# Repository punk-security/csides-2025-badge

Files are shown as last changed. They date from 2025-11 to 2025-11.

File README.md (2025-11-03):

# This is the repo for the CSIDES 2025 crab badge

**This badge is a litle bit funky as we ported the TV-B-GONE code to this badge so you cna use it to turn off most TVs**

This is our most complex badge to date, with quite a few extra components. Soldering it is not easy.

The badge is printed with full-colour UV printed silkscreen. Usually we use JLCPCB for this (and to be honest they're quality is better in our opinion) but they cant print full-colour onto a HASL (silver) finished board. They can only do it with ENIG, which is the gold look. As this crab is meant to be a cyborg, we had to go with PCBWAY this time. 

As with other badges, we made the first design in AutoCAD EAGLE. It's just easy to use, and we're really familiar with it. Then we export it as a gerber and include the silkscreen file manually. This is then provided to PCBWAY. That gerber is in this repo, so you can skip all that.

### TV-B-GONE

For a long time, we've wanted to do a badge which can turn TVs off. A cybord crab, with it's little eye stalk things seemed like our perfect opportunity. It took a lot of work to get the code to work, and tweak the circuitry to get a good range.

Go check out the original code - https://github.com/shirriff/Arduino-TV-B-Gone  
... and the main website- https://www.tvbgone.com/  
... and this instructables - https://www.instructables.com/4-DIY-TV-B-Gone/  
... and this one - https://www.instructables.com/350-DIY-TV-B-Gone-Mico/

We really stood on the shoulders of giants with this, and hopefully added a new and interesting twist. The range is pretty good thanks to a capacitor, which is loosely optimised through trial and error. Essentially you want it to charge as as quickly as possible to not impact the microcontroller, but not discharge completely during a signal transmission. Also size / cost etc.

The badge has a potentiometer so you can control the resistance to the LEDs, and therefore limit their current draw. On fresh batteries, you can go full power and get 20-25m of range. As the batteries run low, the badge will keep crashing as you try to transmit so just tweak the pot.

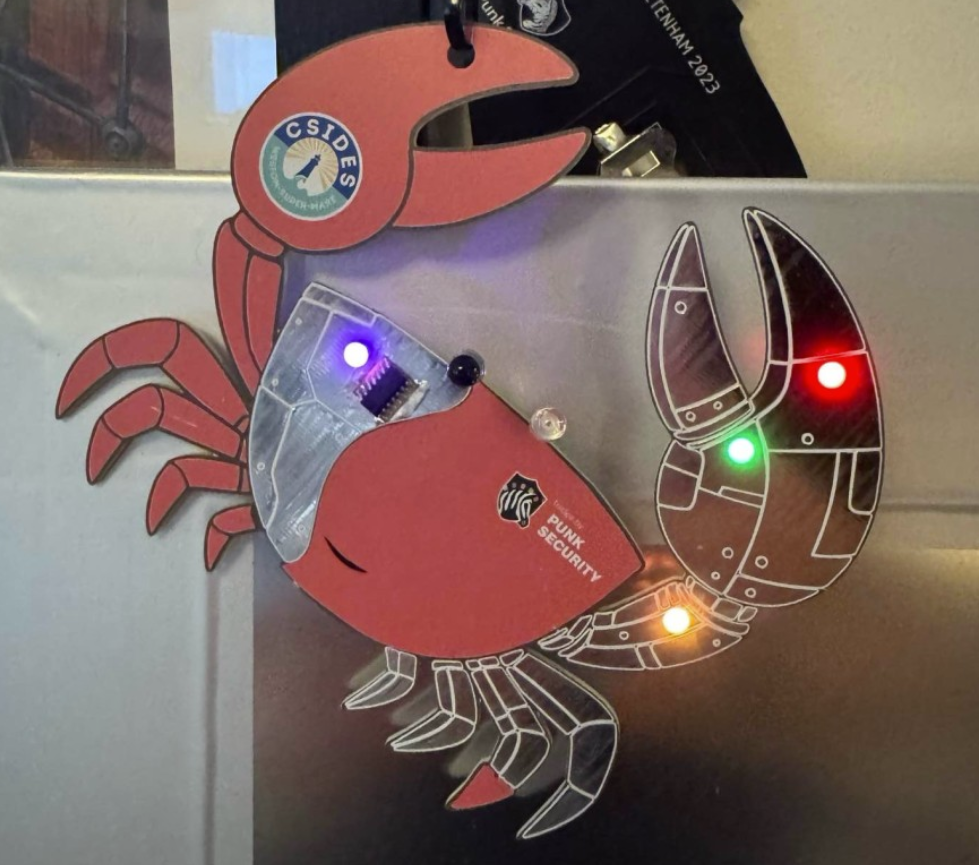
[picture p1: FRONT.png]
PCB Front

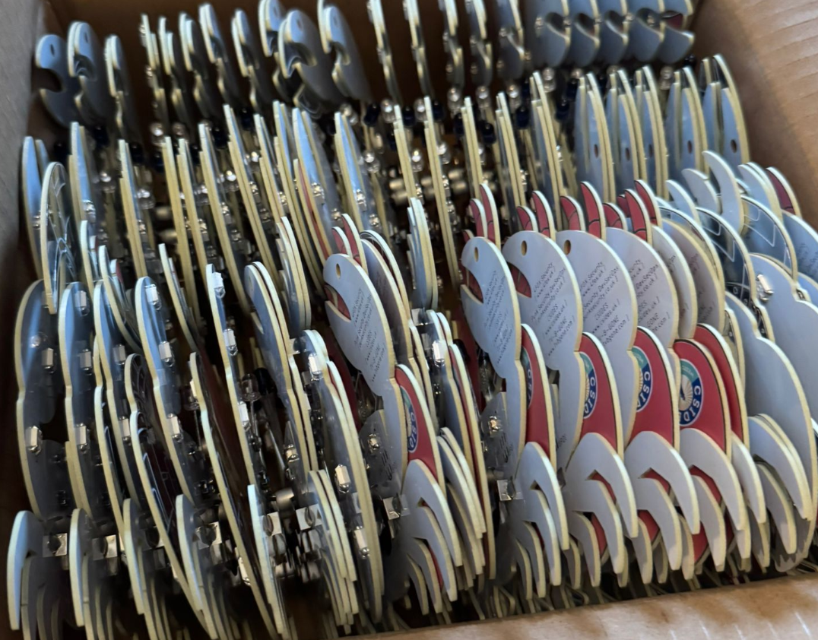
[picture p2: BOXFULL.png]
PCBs


Lots of things in this repo:

- EAGLE.brd: The AutoCAD Eagle board design
- EAGLE.sch: The AutoCAD Eagle circuit schematic
- gerber.zip: the file you can upload to JLCPCB and order your own badge, as is
- SILK_TOP.png: the full colour silkscreen print
- firmware.ino: the arduino code that powers the badge, which you can modify and flash via the SAO connector
- main.h: This is part of the TV-B-GONE code we ported
- WORLD_IR_CODES.h: More of the TV-B-GONE code

## Bill Of Materials

There are a lot of components with this badge. It started out on a breadboard and we tried to keep the part count as low as possible whilst making it actually work! The transistors are a right pain to solder!

This is our first badge using a 1614 microcontroller too. We couldn't fit the code onto the usual ATTINY412.

Essentially its:

* ATTINY1614 microcontroller
* Button - any surface mount button fitting the footprint will work
* NC Button - The reset button it the same footprint as the usual button, but is "open" when pressed. You can skip this and just solder the pads together if you prefer.
* CR2032 battery clip x 2 - surface mount not through hole
* Neopixel 5050 addressable LED - Definitely get the right version of these
* 100 Ohm Trimmer - TC33X-2-101E
* Aishi 100uF Cap - EMK0JM101E83D00R
* NPN transistor SOT-23 - MMBT3904
* 940nm IR LEDS - We had 2 different ones - 10 degree and 40 degree transmission beams

## How does it work?

The badge does the usually blinky modes, but also turns TV off.

To cycle flashy modes, you just short press the button on the badge. 

It can also turn TVs off. To do this, hold the button in for around 3 or 4 seconds and then loose. The badge will start flashing green in one LED. Every LED flash is another European TV off code. When its run out of codes, it will start flashing blue. These are the US codes. When its run out of those, it will return to normally flashy mode. You can exit early at any point by simply pressing the button again.

Holding the button in for a long time will cause the badge to go to sleep. It will do this itself after 60 mins-ish.

## Ordering your own badge

We've uploaded the AutoCAD EAGLE schematic and board design!  You will probably have to do some tweaks to get it working as they're not designed to be standalone exports.

We've also uploaded the gerber.zip.  Take this to PCBWAY and you can order your own exact copies of the board :)

## Writing and flashing code!

We use [MegaTinyCore](https://github.com/SpenceKonde/megaTinyCore) for the arduino interface.

Dev and flashing is done within the Arduino IDE ( < v2 ) using a jtag2updi interface, as discussed [here](https://github.com/SpenceKonde/AVR-Guidance/blob/master/UPDI/jtag2updi.md)

We use [these little usb sticks](https://amzn.eu/d/c0lx0wG), with a 4.7k resistor soldered between the Tx and Rx lines.  

### Installing MegaTinyCore dependencies

This board package can be installed via the board manager in arduino. The boards manager URL is:

`http://drazzy.com/package_drazzy.com_index.json`

1. File -> Preferences, enter the above URL in "Additional Boards Manager URLs"
2. Tools -> Boards -> Boards Manager...
3. Wait while the list loads (takes longer than one would expect, and refreshes several times).
4. Select "megaTinyCore by Spence Konde" and click "Install". For best results, choose the most recent version.

### Setting up the IDE

1. Open the file **firmware.ino** in arduino
2. Select tools > Board > megaTinyCore > ATtiny412/402/212/202
3. Select tools > Chip > ATtiny412
4. Select tools > Clock > 16Mhz internal *(it wont turn off TVs otherwise)*
5. Select tools > Programmer > SerialUPDI SLOW
6. Select tools > Port > ( pick your COM port)

### Flashing firmware
1. Connect the 3v3 pin to 3v on your usb (maybe wedge it in the battery clip)
2. Connect GND to GND
3. Connect UPDI to the RxD port
4. Click Upload button

## How to solder?

It's super tricky!

Essentially, line up the parts and solder them.

We placed the ATTINY1614 on the front as it looked quite cool. It's horrible to solder. Line up the micontroller dimple with the circle, and try not to bridge the pins with the crabs metal background. 

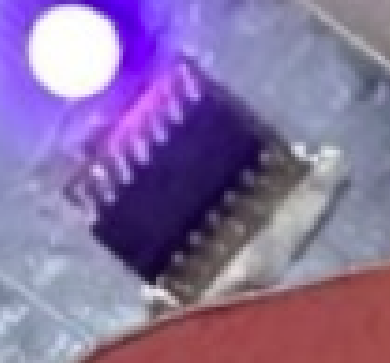
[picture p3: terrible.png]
Terrible


The back is also tricky. Most parts are obvious. The RST button should be a normally closed button, or just solder a bit of wire in its place. The triangles near the LED placements show you how to rotate the LEDs into position.

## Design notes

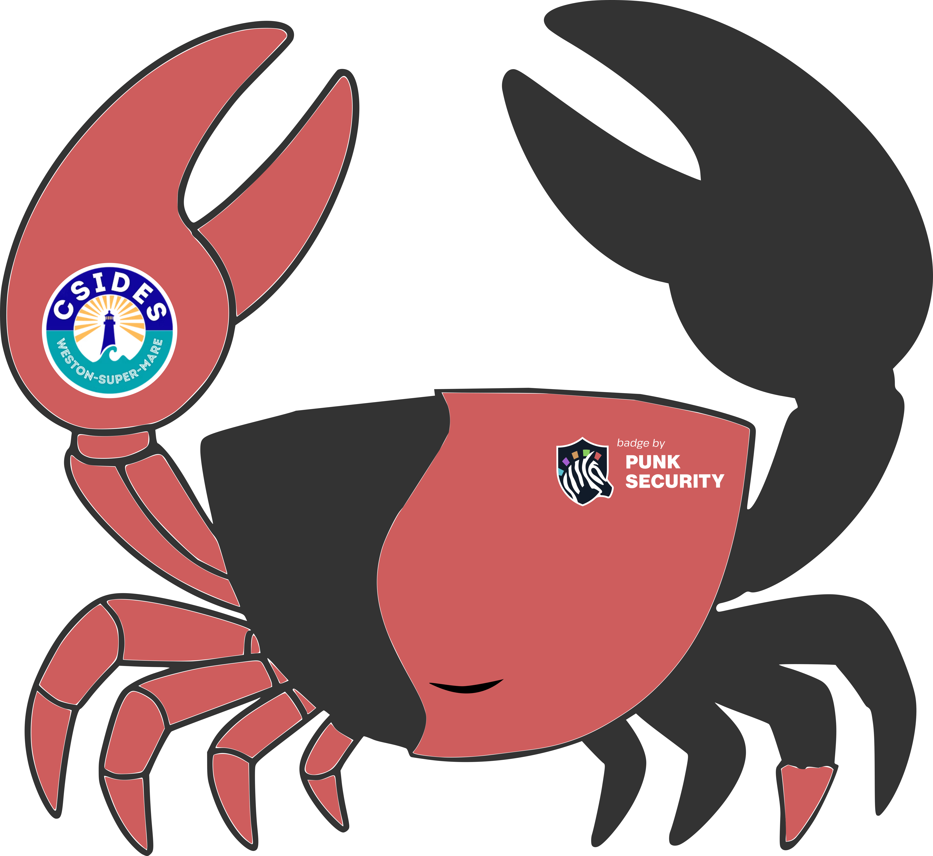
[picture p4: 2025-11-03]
SILK_TOP.png

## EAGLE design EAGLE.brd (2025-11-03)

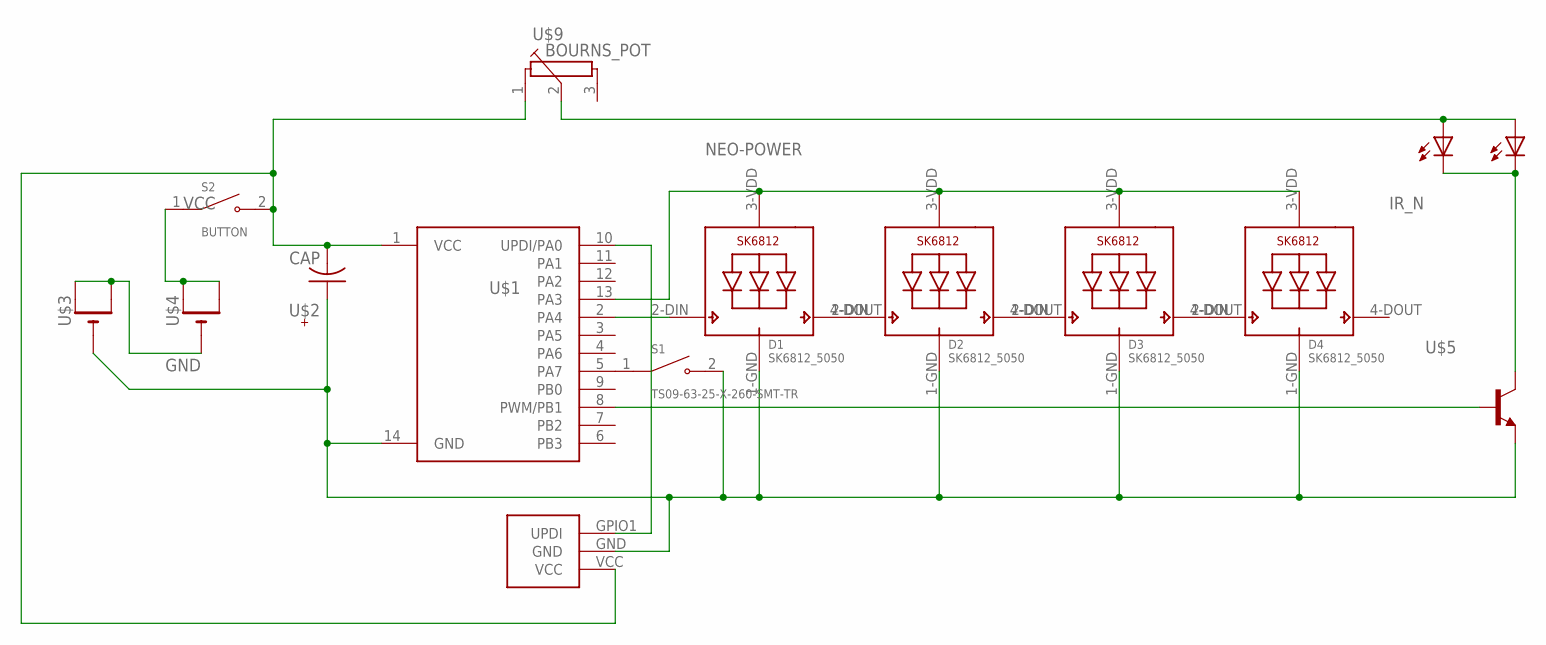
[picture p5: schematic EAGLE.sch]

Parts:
D1, D2, D3, D4: SK6812_5050; SK6812_REVERSE_W_CUT
S1: TS09-63-25-X-260-SMT-TR; SW_TS09-63-25-X-260-SMT-TR
S2: BUTTON; SW_TS09-63-25-X-260-SMT-TR
U$1: ATTINY1614ATTINY1614; SO14
U$2: CAP; UD-6,3X5,8_NICHICON
U$3, U$4: CR2032SMT; CR2032-SMD
U$5: NPN; SOT23
U$6, U$7: LEDSIDESOLDER; LED3MM_5MM_SIDESOLDER
U$8: SAO; SAO_SMD
U$9: BOURNS_POT; 3223W

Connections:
GND: D1.1-GND (GND), D2.1-GND (GND), D3.1-GND (GND), D4.1-GND (GND), S1.2, U$1.14 (GND), U$2.+, U$3.GND, U$5.2 (E), U$8.GND
IR_N: U$5.3 (C), U$6.KN (C), U$7.KN (C)
IR_PWR: U$6.AN (A), U$7.AN (A), U$9.2 (1S)
unnamed: S1.1, U$1.5 (PA7)
unnamed: D1.4-DOUT (DO), D2.2-DIN (DI)
unnamed: D2.4-DOUT (DO), D3.2-DIN (DI)
unnamed: D3.4-DOUT (DO), D4.2-DIN (DI)
unnamed: S2.1, U$4.+$1 (+), U$4.+$2 (+1)
unnamed: U$3.+$1 (+), U$3.+$2 (+1), U$4.GND
NEO-POWER: D1.3-VDD (VDD), D2.3-VDD (VDD), D3.3-VDD (VDD), D4.3-VDD (VDD), U$1.13 (PA3)
NEO_SIGNAL: D1.2-DIN (DI), U$1.2 (PA4)
PWM: U$1.8 (PWM/PB1), U$5.1 (B)
UPDI: U$1.10 (UPDI/PA0), U$8.GPIO1 (UPDI)
VCC: S2.2, U$1.1 (VCC), U$2.-, U$8.VCC, U$9.1 (1A)

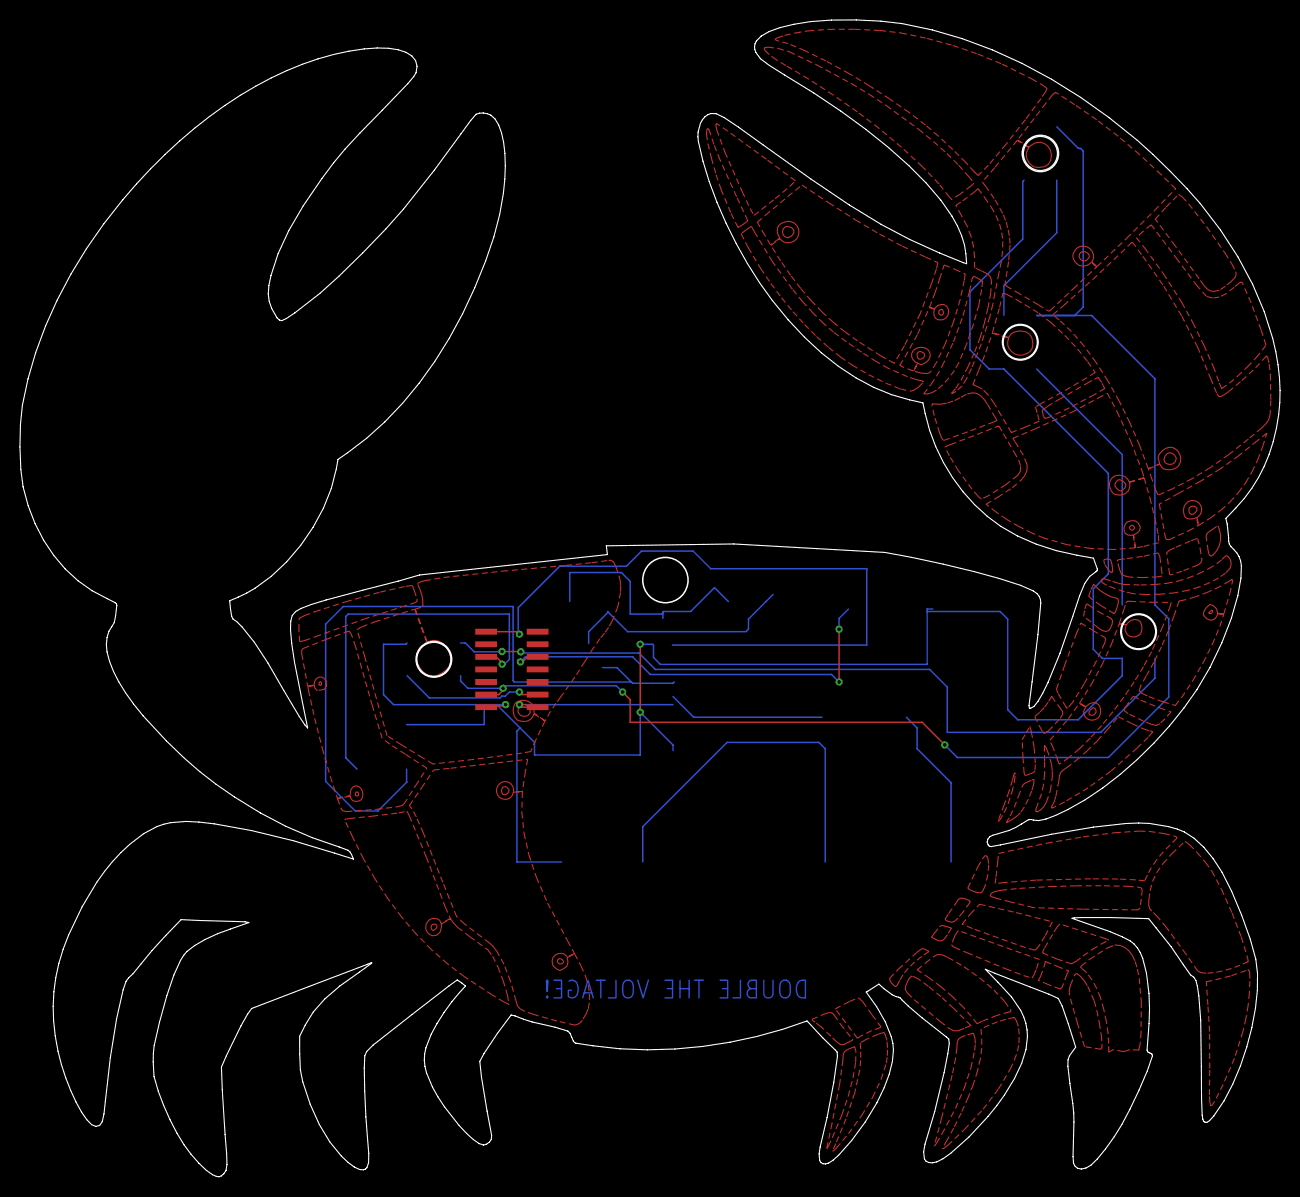
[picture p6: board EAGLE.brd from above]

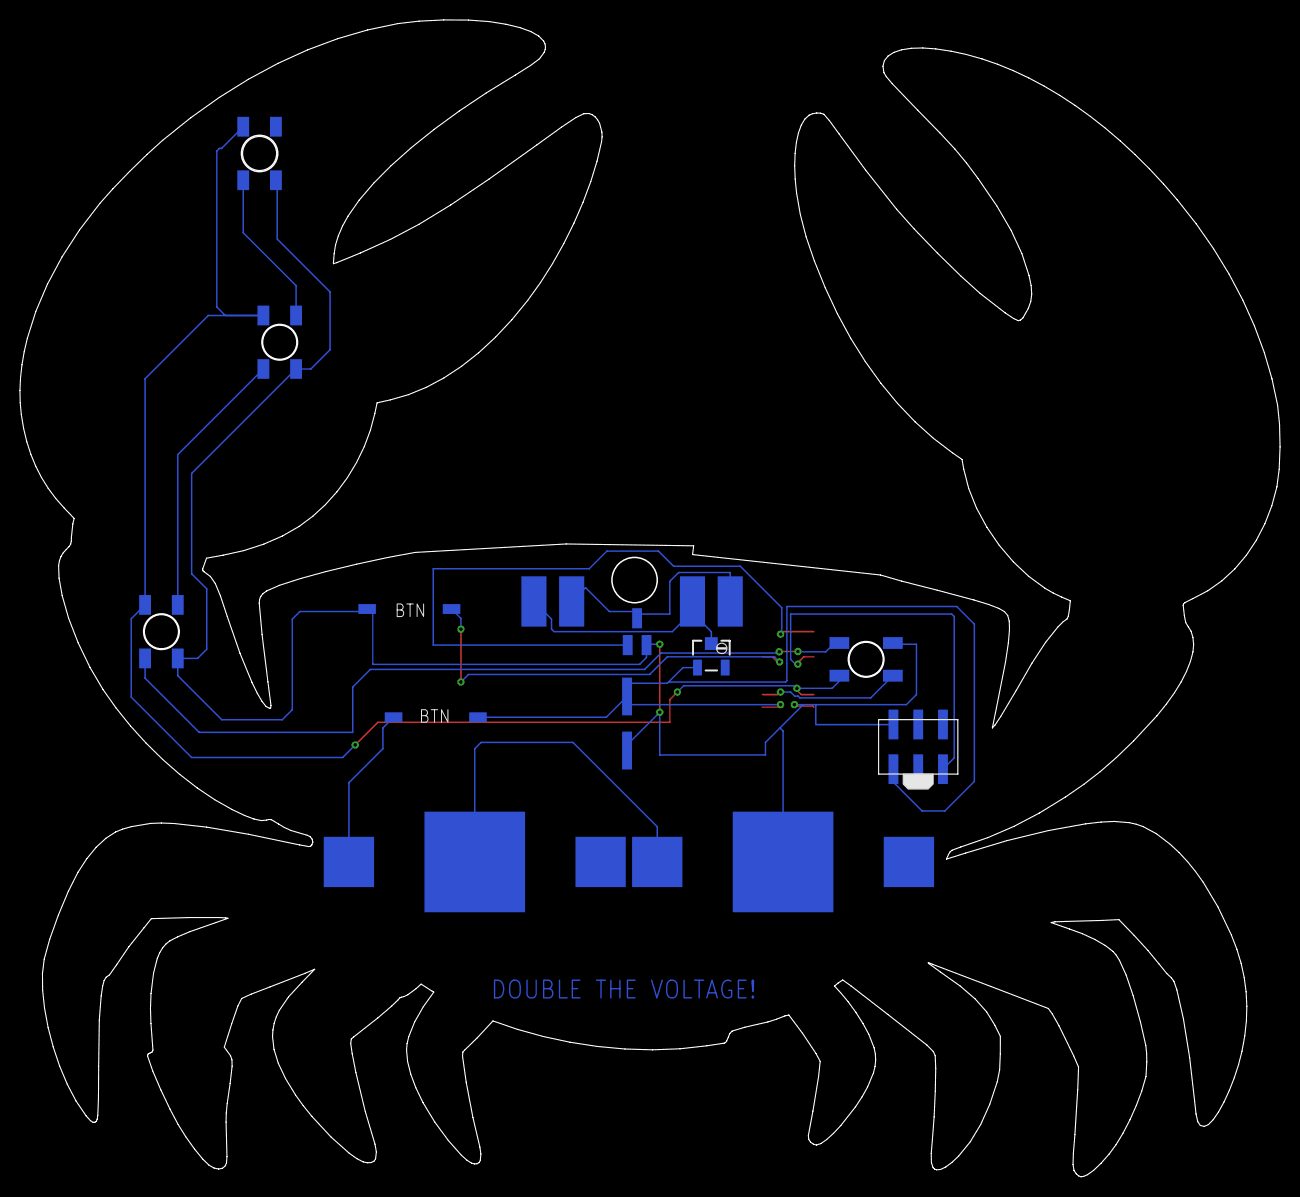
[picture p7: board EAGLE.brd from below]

Board: 2 copper layers, 127.2 x 116.8 mm, 15 parts (14 on the bottom side), 14 nets.

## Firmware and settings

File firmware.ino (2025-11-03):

#include <avr/io.h>
#include <avr/interrupt.h>
#include <avr/sleep.h>
#include <util/delay.h>
#include <avr/pgmspace.h>

/// FLASH at 16Mhz otherwise it no worky
/// Set to starutp time 64 ms to prevent reset button corruption

#include "WORLD_IR_CODES.h"

// ==== CONFIGURATION ====

// Pin definitions
#define IRLED_PIN   PIN_PB1  // TCA0 WO1
#define TRIGGER_PIN PIN_PA7
#define NEOPIXEL_DATA PIN_PA4
#define NEOPIXEL_PWR PIN_PA3


# define WAKE_TIME_MS 2700000 // 60 mins

// External IR code data
extern const IrCode* const EUpowerCodes[] PROGMEM;
extern uint8_t num_EUcodes;
extern const IrCode* const NApowerCodes[] PROGMEM;
extern uint8_t num_NAcodes;

// ==== GLOBALS ====
uint8_t bitsleft_r = 0;
uint8_t bits_r = 0;
const uint8_t* code_ptr;

// ==== FUNCTION PROTOTYPES ====
void setupPWM();
void xmitCodeElement(uint16_t ontime, uint16_t offtime, uint8_t usePWM);
void delay_ten_us(uint16_t us10);
uint8_t read_bits(uint8_t count);
void sendIRCode(const uint8_t* code_data);
void sendAllCodes();

// NEOPIXELS
#include <tinyNeoPixel_Static.h>
#define NUMLEDS 4
byte pixels[NUMLEDS * 3];
tinyNeoPixel strip = tinyNeoPixel(NUMLEDS, NEOPIXEL_DATA, NEO_GRB, pixels);

// ==== SETUP ====

#include <avr/sleep.h>

void RTC_init()
{
  /* Initialize RTC: */
  while (RTC.STATUS > 0)
  {
    ;                                   /* Wait for all register to be synchronized */
  }
  RTC.CLKSEL = RTC_CLKSEL_INT1K_gc;    /* 1kHz Internal Ultra-Low-Power Oscillator (OSCULP32K) */
}

void mini_sleep( uint8_t period = RTC_PERIOD_CYC16_gc)
{
  // default timer is about 16ms
  RTC.PITINTCTRL = RTC_PI_bm;  // Enable RTC interrupt
  RTC.PITCTRLA = period | RTC_PITEN_bm; // Set timer to 2s
  set_sleep_mode(SLEEP_MODE_PWR_DOWN);
  sleep_enable();
  sleep_cpu();
  RTC.PITINTCTRL = ~(RTC_PI_bm); // Disable RTC interrupt
}

ISR(RTC_PIT_vect)
{
  RTC.PITINTFLAGS = RTC_PI_bm;  // Clear RTC interrupt flag otherwise keep coming back here
}


void sleep()
{
  set_sleep_mode(SLEEP_MODE_PWR_DOWN);
  PORTA.PIN7CTRL = PORT_PULLUPEN_bm | PORT_ISC_LEVEL_gc; // enable pullup and interrupt
  digitalWrite(NEOPIXEL_PWR, LOW); // turn off LED power rail
  sleep_enable();
  sleep_cpu();
  // sleep resumes here
  PORTA.PIN7CTRL = PORT_PULLUPEN_bm; // renable pullup but no interrupt
  digitalWrite(NEOPIXEL_PWR, HIGH);  // turn on LED power rail
  setupTCAO();
  setupPWM();
}

ISR(PORTA_PORT_vect) {
  PORTA.INTFLAGS = PORT_INT7_bm; // Clear Pin 7 interrupt flag otherwise keep coming back here
}

void setupTCAO()
{
  takeOverTCA0();   
  PORTMUX.CTRLC &= 1 << 1;
}

void setup() {
  ADC0.CTRLA &= ~ADC_ENABLE_bm; 
  pinMode(IRLED_PIN, OUTPUT);
  pinMode(NEOPIXEL_PWR, OUTPUT);
  pinMode(NEOPIXEL_DATA, OUTPUT);
  pinMode(TRIGGER_PIN, INPUT_PULLUP);
  digitalWrite(NEOPIXEL_PWR, HIGH);
  strip.begin();
//  // Set IR LED pin as output
  PORTA.DIRSET = (1 << IRLED_PIN);
  setupTCAO();
  setupPWM();
  RTC_init();
}

void setupPWM() {


  // Configure TCA0 for 38kHz freq PWM on WO0
  TCA0.SINGLE.CTRLB   = (TCA_SINGLE_CMP1EN_bm | TCA_SINGLE_WGMODE_SINGLESLOPE_gc);
  TCA0.SINGLE.PER = 420;     // 16MHz / 8 / 210 ≈ 9.5kHz × 4 = 38kHz
  TCA0.SINGLE.CMP1 = 70;     // ~33% duty cycle
  TCA0.SINGLE.CTRLA = TCA_SINGLE_CLKSEL_DIV8_gc; // Enable only in xmitCodeElement
  //TCA0.SINGLE.CTRLA   = TCA_SINGLE_ENABLE_bm;
}

void setAllPixels(int r, int g, int b, bool show = false)
{
  for (int i = 0; i < NUMLEDS; i++) 
  {
    strip.setPixelColor(i,r,g,b);
  }
  if(show)
    strip.show();
}

#define RED 30,0,0
#define GREEN 0,8,0
#define BLUE 0,0,30
#define CSIDES_BLUE 0,40,30
#define ORANGE 20,8,0
#define PINK 6,0,4
#define PURPLE 6,0,15
#define OLIVE 2,2,0
#define YELLOW 18,12,0
#define YELLOWGREEN 20,30,20
#define OFF 0,0,0

int rainbow_rotate(int x)
{
  strip.setPixelColor((x+4) % 5,RED);
  strip.setPixelColor((x+3) % 5,GREEN);
  strip.setPixelColor((x+2) % 5,ORANGE);
  strip.setPixelColor((x+1) % 5,PURPLE);
  strip.setPixelColor(x % 5,BLUE);
  strip.show();
  return 200;
}

int red_eye (int x)
{
  setAllPixels(OFF);
  strip.setPixelColor(0,(x % 40) * 5,0,0);
  strip.show();
  return 20;
}

int power_up (int x)
{
  int n = x % 60;
  int s = n % 10;
  setAllPixels(OFF);
  switch (n){
    case 0 ... 9:
      strip.setPixelColor(0, 0, s * 20, 0);
      break;
    case 10 ... 19:
      strip.setPixelColor(0, 0, 255, 0);
      strip.setPixelColor(1, 0, s * 20, 0);
      break;
    case 20 ... 29:
      strip.setPixelColor(0, 0, 255, 0);
      strip.setPixelColor(1, 0, 255, 0);
      strip.setPixelColor(2, 0, s * 20, 0);
      break;
    case 30 ... 39:
      strip.setPixelColor(0, 0, 255, 0);
      strip.setPixelColor(1, 0, 255, 0);
      strip.setPixelColor(2, 0, 255, 0);
      strip.setPixelColor(3, 0, s * 20, 0);
      break;
    default:
      setAllPixels(0,255,0);
  }
  strip.show();
  return 50;
}

int alternate(int x, int r, int g, int b, int r2, int g2, int b2, int ret = 100)
{
  if(x % 2 == 0)
  {
    strip.setPixelColor(0,r,g,b);
    strip.setPixelColor(1,r2,g2,b2);
    strip.setPixelColor(2,r,g,b);
    strip.setPixelColor(3,r2,g2,b2);
  }
  else
  {
    strip.setPixelColor(0,r2,g2,b2);
    strip.setPixelColor(1,r,g,b);
    strip.setPixelColor(2,r2,g2,b2);
    strip.setPixelColor(3,r,g,b);
  }
  strip.show();
  return ret;
}

int p_4fox(int x)
{
  setAllPixels(10,10,10);
  int n = x % 4;
    strip.setPixelColor(n, ORANGE);
  strip.show();
  return 200;
}

int p_4fox_2(int x)
{
  setAllPixels(ORANGE);
  int n = x % 4;
    strip.setPixelColor(n, 10,10,10);
  strip.show();
  return 200;
}

int cyberis(int x)
{
  strip.setPixelColor( x % 4,       0,0,10);
  strip.setPixelColor( (x + 1) % 4, 0,5,10);
  strip.setPixelColor( (x + 2) % 4, 0,10,0);
  strip.setPixelColor( (x + 3) % 4, 9,4,0);
  strip.show();
  return 30;
}

int prism(int x)
{
  int n = x % 10 + 10;
  setAllPixels(0,5 * n, 3 * n, true);
  return 20;
}

int punk_2(int x)
{
  int n = x % 5;
  switch (n)
  {
    case 0:
      setAllPixels(RED, true); break;
    case 1:
      setAllPixels(GREEN, true); break;
    case 2:
      setAllPixels(ORANGE, true); break;
    case 3:
      setAllPixels(PURPLE, true); break;
    case 4:
      setAllPixels(BLUE, true); break;
  }
  return 500;
}

int police(int x)
{
  if( x % 2 == 0)
  {
    strip.setPixelColor(0,255,0,0);
    strip.setPixelColor(3,255,0,0);
    strip.setPixelColor(2,0,0,255);
    strip.setPixelColor(1,0,0,255);
  }
  else
  {
    strip.setPixelColor(0,0,0,255);
    strip.setPixelColor(3,0,0,255);
    strip.setPixelColor(2,255,0,0);
    strip.setPixelColor(1,255,0,0);
  }
  strip.show();
  return 200;
}

int knightrider(uint8_t i, int r, int g, int b, int r2, int g2, int b2)
{
  setAllPixels(r2,g2,b2);
  int n = i % 10;
  if (n < 4)
  {
    strip.setPixelColor(n,r,g,b);
  }
  else if (n > 5)
  {
    strip.setPixelColor(10-n,r,g,b);
  }
  strip.show();
  return 50;
}

int glitch(uint8_t i){
  int b = i % 10;
  int l = i / 50;
  setAllPixels(OFF);
  strip.setPixelColor(l, 0 , 30 -b, 20 - b);
  strip.show();
  return 10;
}

int csides(int x)
{
  int g = x % 40;
  if (g > 20) g = 40 - g;
  strip.setPixelColor(0,CSIDES_BLUE);
  strip.setPixelColor(1,CSIDES_BLUE);
  strip.setPixelColor(2,0,g,30);
  strip.setPixelColor(3,BLUE);
  strip.show();
  if (g == 0)
  {
    return 500;
  }
  return 100;
}

uint16_t time_pin_low(uint16_t max_ms)
{
  // blocking for up to max_ms
for (int i = 0; i < 20; i++) {
  if (digitalRead(TRIGGER_PIN) == HIGH) {
    return 0;
  }
  delay(5);
}
  uint16_t t = 100;
  while(digitalRead(TRIGGER_PIN) == LOW)
  {
    delay(5);
    t = t + 5;
    if ( t > max_ms )
      return(max_ms);
  }
  return(t);
}
// ==== MAIN LOOP ====

void loop() {
  int mode = 0;
  int interval;
  uint16_t button_low_time = 0;
  uint32_t total_interval = 0;
  int i = 0;
  while(true)
  {
    if ( mode == 0 )
    {
      interval = csides(i);
    }
    else if ( mode == 1)
    {
      interval = rainbow_rotate(i);
    }
    else if ( mode == 2)
    {
      interval = police(i);
    }
    else if ( mode == 3)
    {
      interval = red_eye(i);
    }
    else if ( mode == 4)
    {
      interval = power_up(i);
    }
    else if ( mode == 5)
    {
      interval = alternate(i,PINK,PURPLE,40);
    }
    else if ( mode == 6)
    {
      interval = p_4fox(i);
    }
    else if ( mode == 7)
    {
      interval = p_4fox_2(i);
    }
    else if ( mode == 8)
    {
      interval = knightrider(i,RED, OFF);
    }
    else if ( mode == 9)
    {
      interval = prism(i);
    }
    else if ( mode == 10)
    {
      interval = punk_2(i);
    }
    else if ( mode == 11)
    {
      interval = glitch(i);
    }
    else if ( mode == 12)
    {
      interval = knightrider(i,GREEN, OFF);
    }
    else if ( mode == 13)
    {
      interval = cyberis(i);
    }
    else
    {
      mode = 0;
      continue;
    }
    i++;
    // This section breaks down the sleep interval to catch button presses
    total_interval = total_interval + interval;
    while(interval > 0)
    {
      mini_sleep();
      interval = interval - 10;
      button_low_time = time_pin_low(3000);
      if (button_low_time > 200)
      {
       /*
       * MAIN MENU
       * NO PRESS = CONTINUE
       * SHORT PRESS = CHANGE FLASHY MODE
       * MEDIUM PRESS = SEND CODES
       * LONG PRESS = SLEEP
       */
        if (button_low_time == 3000)
        {
          setAllPixels(RED,true);
          while(digitalRead(TRIGGER_PIN) == LOW)
          {
            // WAIT FOR RELEASE BEFORE SLEEPING otherwise we wake back up!
            delay(5);
          }
          delay(50); //DEBOUNCE
          sleep();
        }
        else if (button_low_time > 500)
        {
          sendAllCodes();
          digitalWrite(NEOPIXEL_PWR, HIGH);
        }
        else
        {
          mode++;
        }
        // reset timer
        i = 0;
        total_interval = 0;
      }

    }
    // At the end of each interval, see if we need to sleep
    if (total_interval > WAKE_TIME_MS)
    {
      total_interval = 0;
      i = 0;
      sleep();
    }
  }
}

// ==== CORE FUNCTIONS ====

void flash(int r, int g, int b)
{
    strip.setPixelColor(0, r,g,b);
    strip.setPixelColor(1, 0,0,0);
    strip.setPixelColor(2, 0,0,0);
    strip.setPixelColor(3, 0,0,0);
    digitalWrite(NEOPIXEL_PWR,HIGH);
    delay(1);
    strip.show();
    mini_sleep(RTC_PERIOD_CYC32_gc);
    digitalWrite(NEOPIXEL_PWR,LOW);
    mini_sleep(RTC_PERIOD_CYC512_gc);
}

void sendAllCodes() {
  flash(0,1,0);
  for (uint8_t i = 0; i < num_EUcodes; i++) {
    const IrCode* code = (const IrCode*)pgm_read_word(&EUpowerCodes[i]);
    sendIRCode((const uint8_t*)code);
    flash(1,0,0);
    if (time_pin_low(2000) > 50)
    {
      return;
    }
  }
  for (uint8_t i = 0; i < num_NAcodes; i++) {
    const IrCode* code = (const IrCode*)pgm_read_word(&NApowerCodes[i]);
    sendIRCode((const uint8_t*)code);
    flash(0,0,1);
    if (time_pin_low(2000) > 50)
    {
      return;
    }
  }
}

void sendIRCode(const uint8_t* code_data) {
  const uint8_t freq = pgm_read_byte(code_data++);
  const uint8_t numpairs = pgm_read_byte(code_data++);
  const uint8_t bitcompression = pgm_read_byte(code_data++);

  const uint16_t* time_ptr = (const uint16_t*)pgm_read_word(code_data);
  code_data += 2;

  code_ptr = (const uint8_t*)pgm_read_word(code_data);

  bitsleft_r = 0;

  for (uint8_t k = 0; k < numpairs; k++) {
    uint8_t index = read_bits(bitcompression);
    uint16_t ti = index * 2;
    uint16_t ontime = pgm_read_word(&time_ptr[ti]);
    uint16_t offtime = pgm_read_word(&time_ptr[ti + 1]);

    xmitCodeElement(ontime, offtime, (freq != 0));
  }

  bitsleft_r = 0;
}

void xmitCodeElement(uint16_t ontime, uint16_t offtime, uint8_t usePWM) {
  if (usePWM) {
    TCA0.SINGLE.CTRLA = TCA_SINGLE_ENABLE_bm; // enable PWM
  } else {
    VPORTA.OUT |= (1 << IRLED_PIN);
  }

  delay_ten_us(ontime);

  if (usePWM) {
    TCA0.SINGLE.CTRLA &= ~TCA_SINGLE_ENABLE_bm; // disable PWM
    VPORTA.OUT &= ~(1 << IRLED_PIN);
  } else {
    VPORTA.OUT &= ~(1 << IRLED_PIN);
  }

  delay_ten_us(offtime);
}

uint8_t read_bits(uint8_t count) {
  uint8_t tmp = 0;
  for (uint8_t i = 0; i < count; i++) {
    if (bitsleft_r == 0) {
      bits_r = pgm_read_byte(code_ptr++);
      bitsleft_r = 8;
    }
    bitsleft_r--;
    tmp |= ((bits_r >> bitsleft_r) & 1) << (count - 1 - i);
  }
  return tmp;
}

void delay_ten_us(uint16_t us10) {
  while (us10--) _delay_us(10);
}

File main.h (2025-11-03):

// Taken from https://github.com/shirriff/Arduino-TV-B-Gone

/*
Last Updated: 22 Oct. 2016
By Gabriel Staples, http://www.ElectricRCAircraftGuy.com 
-My contact info is available by clicking the "Contact Me" tab at the top of my website.
*/

#include <avr/pgmspace.h>

// The TV-B-Gone for Arduino can use either the EU (European Union) or the NA (North America) database of POWER CODES
// EU is for Europe, Middle East, Australia, New Zealand, and some countries in Africa and South America
// NA is for North America, Asia, and the rest of the world not covered by EU

// Two regions!
#define NA 1 //set by a HIGH on REGIONSWITCH pin
#define EU 0 //set by a LOW on REGIONSWITCH pin

// What pins do what
#define LED LED_BUILTIN //LED indicator pin (usually 13)
#define IRLED 3         //the IR sender LED 
#define TRIGGER 2       //the button pin; NB: this pin is "hard-coded" in the sleepNow() function in the primary .ino file by means of using external interrupt 0, which is hard-wired to pin 2
#define REGIONSWITCH 5  //HIGH (1) = NA, LOW (0) = EU; Pin 5 (REGIONSWITCH) is HIGH (via in input pullup resistor) for North America, or you (the user) must wire it to ground to set the codes for Europe.

// Lets us calculate the size of the NA/EU databases
#define NUM_ELEM(x) (sizeof (x) / sizeof (*(x)));

// set define to 0 to turn off debug output
#define DEBUG 0
#define DEBUGP(x) if (DEBUG == 1) { x ; }

// Shortcut to insert single, non-optimized-out nop
#define NOP __asm__ __volatile__ ("nop")

// Tweak this if neccessary to change timing
// -for 8MHz Arduinos, a good starting value is 11
// -for 16MHz Arduinos, a good starting value is 25
#define DELAY_CNT 25

// Makes the codes more readable. the OCRA is actually
// programmed in terms of 'periods' not 'freqs' - that
// is, the inverse!
#define freq_to_timerval(x) (F_CPU / 8 / x - 1)

// The structure of compressed code entries
struct IrCode {
  uint8_t timer_val;
  uint8_t numpairs;
  uint8_t bitcompression;
  uint16_t const *times;
  uint8_t const *codes;
};
